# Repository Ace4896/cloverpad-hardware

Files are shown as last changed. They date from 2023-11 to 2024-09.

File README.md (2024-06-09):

# Cloverpad - Hardware

**NOTE**: This project is still a work-in-progress, this note will be removed once it's ready!

This repository contains the hardware designs for the Cloverpad, a 3-key keypad for osu! themed after [MORE MORE JUMP!](https://www.sekaipedia.org/wiki/MORE_MORE_JUMP!) from Project Sekai.

... picture of finished keypad ...

There are two PCB variants for this keypad:

- **Cloverpad HE**: PCB for use with hall effect switches (e.g. Wooting Lekker, Gateron KS-20), themed after [Haruka Kiritani](https://www.sekaipedia.org/wiki/Kiritani_Haruka).
- **Cloverpad MX**: PCB for use with regular MX-style mechanical switches, themed after [Minori Hanasato](https://www.sekaipedia.org/wiki/Hanasato_Minori).

## Usage

Make sure you have the following things installed:

- [FreeCAD 0.21](https://www.freecad.org/)
- [KiCad 8](https://www.kicad.org/) with the following plugins:
  - [marbastlib Keyboard Footprints](https://github.com/ebastler/marbastlib)
  - [KiCad JLCPCB Tools](https://github.com/Bouni/kicad-jlcpcb-tools) (if you're using JLC for manufacturing the PCB)

Clone the repository:

```bash
git clone git@github.com:Cloverpad/cloverpad-hardware.git
```

Then navigate to the folder for the revision you're interested in:

- [Rev. 2](./rev2)
- [Rev. 1](./rev1) (Cloverpad MX only; not recommended due to design flaws)

## Additional Files

These project files were used to help design the case and PCB:

- [**assets**](./assets): Miscellaneous assets - logos, character emotes etc.
- [**notes**](./notes): Personal notes for this project - you may find them useful if you're designing a keypad/keyboard of your own
- [**kle**](./kle): Keypad layouts generated by [Keyboard Layout Editor](http://www.keyboard-layout-editor.com/)

## Licensing

This project is licensed under [CERN-OHL-S-2.0](./LICENSE).

Below is a list of assets used from other projects:

- [Project Sekai: Colourful Stage!](https://www.colorfulstage.com/)
  - © SEGA / © Colorful Palette Inc. / © Crypton Future Media, INC.
  - This is a fan project and has no affiliation with SEGA, Colorful Palette, or Crypton Future Media.
  - Assets from MORE MORE JUMP! and its characters are used in the PCB designs.
- [ConstantinoSchillebeeckx/cherry-mx-switch](https://github.com/ConstantinoSchillebeeckx/cherry-mx-switch)
  - [MIT License](https://github.com/ConstantinoSchillebeeckx/cherry-mx-switch/blob/master/LICENSE)
  - The Cherry MX Switch 3D model is used in the minimal PCB.
- [ebastler/marbastlib](https://github.com/ebastler/marbastlib)
  - [CERN-OHL-P-2.0 License](https://github.com/ebastler/marbastlib/blob/main/LICENSE)
  - Various KiCad symbols and footprints are used in the PCB designs and the minimal PCB.

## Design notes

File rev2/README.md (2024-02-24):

# Cloverpad rev. 2

**NOTE**: This revision is still a work-in-progress, this note will be removed once it's ready!

This folder contains the hardware designs for the Cloverpad rev. 2. This is an incremental improvement over rev. 1, which resolves various issues with the 3D printed case.

Features:

- RP2040 MCU
- Cloverpad HE supports hot-swappable MX-style hall effect switches
- Cloverpad MX supports hot-swappable MX-style digital switches
- 3D printed case w/ threaded inserts

Required parts (for reference):

- 3D printed case + PCB
- USB Type-C cable
- 8x M2x6mm screws
- 8x M2x3mm threaded inserts
- Rubber feet

## Design Files

- [`cloverpad-case.FCStd`](./cloverpad-case.FCStd): FreeCAD 0.21 project for the 3D printed case.
- [`cloverpad-he-pcb`](./cloverpad-he-pcb): KiCad 8 project for the Cloverpad HE rev. 2 PCB.
- [`cloverpad-mx-pcb`](./cloverpad-mx-pcb): KiCad 8 project for the Cloverpad MX rev. 2 PCB.

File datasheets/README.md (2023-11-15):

# Datasheets

This folder contains datasheets for any important parts used in this project. The latest versions can be found on the manufacturers websites.

- **Hall Sensors**: [DRV5056](./drv5056/)
- **Key Switches**: [KS-20](./ks-20/) 
- **Microcontroller**: [RP2040](./rp2040/)

## Hall Sensor Compatibility

**NOTE**: As far as I'm aware, the KS-20 and Lekker switches use the same mechanism, and the only differences are branding, colours and spring weight. It should be possible to use them interchangably.

In the KS-20's datasheet, there are a few key pieces of information:

- Total Travel: 4.1 +/- 0.2mm
- Hall Sensor Placement: Back of PCB
- Orientation of Permanent Magnet: North pole at bottom of switch
- Magnetic Flux Density @ North Pole:
  - Initial Position: 102 +/- 15G
  - Total Travel Position: 905 +/- 80G

Based on the hall sensor placement and the orientation of the permanent magnet, it generates a positive field. In the diagram below (credit: [Texas Instruments - SLYT826](https://www.ti.com/document-viewer/lit/html/slyt826)), we can see this in the top-right case:

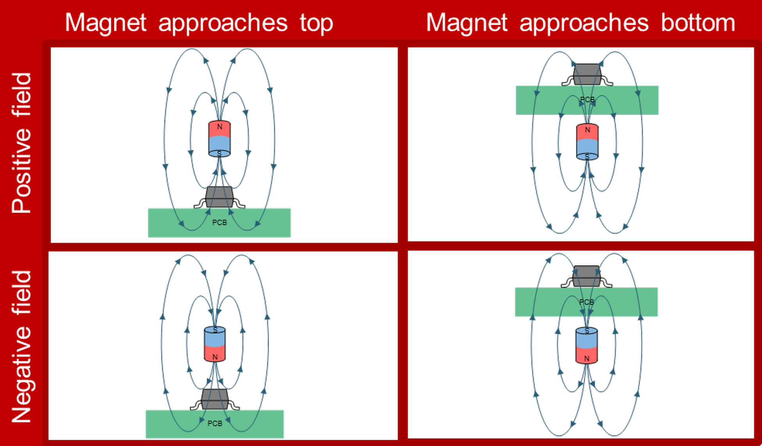
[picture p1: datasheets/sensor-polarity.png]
Sensor Polarity


This means that the hall sensor used needs to have the following properties:

- Detect a positive magnetic field (sometimes referred to as "south active")
- Produce a linear output so we can get analog readings
- Have a magnetic range that covers the maximum magnetic flux
- (Ideally) Unipolar i.e. reacts to only one pole / field direction
  - Technically, we can use a bipolar sensor that reacts to both poles, but we lose half of the resolution to a range of values that we won't use

The DRV5056A3 was chosen as it meets most of this criteria:

- Has a variant that can detect positive fields
- Generates a linear output
- Has a magnetic range of 79mT (790G)
- Is unipolar

The only downside is that we can't detect the full travel distance, since the analog output will be saturated before we reach the end of a keypress. If we wanted to detect the whole keypress, we could use the DRV5056A4 instead (magnetic range of 158mT / 1580G), but we lose a large section of the output voltage range as our maximum magnetic flux density is only 905G.

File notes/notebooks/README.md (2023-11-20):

# Jupyter Notebooks

This folder contains any Jupyter Notebooks I used while figuring out the calculations needed for this project.

- [magnet-distance](./magnet-distance.ipynb): Determining magnet distance from the magnetic flux value.

## Usage

You can preview these notebooks with GitHub's online viewer, but if you want to view/edit them locally, some setup is needed:

- Install Python 3.12 or higher
- [Create a virtual environment and activate it](https://packaging.python.org/en/latest/guides/installing-using-pip-and-virtual-environments/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):

```bash
python -m venv .venv

# Bash
source .venv/bin/activate

# PowerShell
.\.venv\bin\Activate.ps1
```

- Install requirements with `pip`:

```bash
pip install -r requirements.txt
```

- Start up Jupyter:

```bash
jupyter notebook
```

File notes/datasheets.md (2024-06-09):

# Datasheets

This folder contains datasheets several important parts used in this project. The latest versions can be found on the manufacturer websites.

- **Hall Sensors**:
  - [DRV5056](./drv5056/)
  - [SS39ET](./ss39et/)
- **Key Switches**:
  - [KS-20](./ks-20/) (original version)
- **Microcontrollers**:
  - [RP2040](./rp2040/)
- **Shunt Voltage References**:
  - [LM4040](./lm4040/)

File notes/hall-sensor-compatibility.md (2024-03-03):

# Hall Sensor Compatibility

**NOTE**: As far as I'm aware, the KS-20 and Lekker switches use the same mechanism, and the only differences are branding, colours and spring weight. It should be possible to use them interchangably.

In the KS-20's datasheet, there are a few key pieces of information:

- Total Travel: 4.1 +/- 0.2mm
- Hall Sensor Placement: Back of PCB
- Orientation of Permanent Magnet: North pole at bottom of switch
- Magnetic Flux Density @ North Pole:
  - Initial Position: 102 +/- 15G
  - Total Travel Position: 905 +/- 80G

Based on the hall sensor placement and the orientation of the permanent magnet, it generates a positive field. In the diagram below (credit: [Texas Instruments - SLYT826](https://www.ti.com/document-viewer/lit/html/slyt826)), we can see this in the top-right case:

Sensor Polarity

This means that the hall sensor used needs to have the following properties:

- Detect a positive magnetic field (sometimes referred to as "south active")
- Produce a linear output so we can get analog readings
- Have a magnetic range that covers the maximum magnetic flux
- (Ideally) Unipolar i.e. reacts to only one pole / field direction
  - Technically, we can use a bipolar sensor that reacts to both poles, but we lose half of the resolution to a range of values that we won't use

The DRV5056A3 was chosen as it meets most of the criteria:

- Has a variant that can detect positive fields
- Generates a linear output
- Has a magnetic range of 78mT (780G) at 3.3V
  - Technically, this range is not large enough, but in the ideal case, we'd only lose the last 0.2mm of travel on average, which makes this viable in practice
- Is unipolar

The DRV5056A4 would also work and be able to track the entire keystroke, but its reduced resolution means that 0.1mm precision is harder to achieve, especially at the top of the keystroke where the ADC values are smaller.

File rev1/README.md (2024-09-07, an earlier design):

# Cloverpad rev. 1

**NOTE**: I don't recommend using these designs; see the list [known issues](#known-issues) below.

This folder contains the hardware designs for the Cloverpad rev. 1.

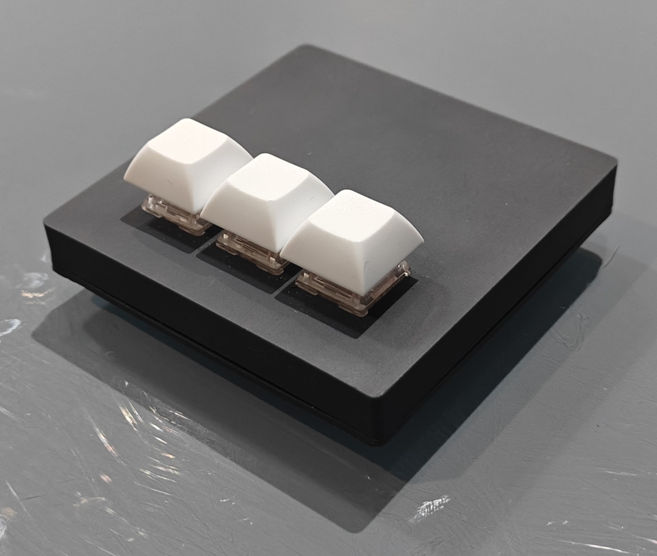
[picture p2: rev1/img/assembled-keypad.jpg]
Assembled Keypad

<br />
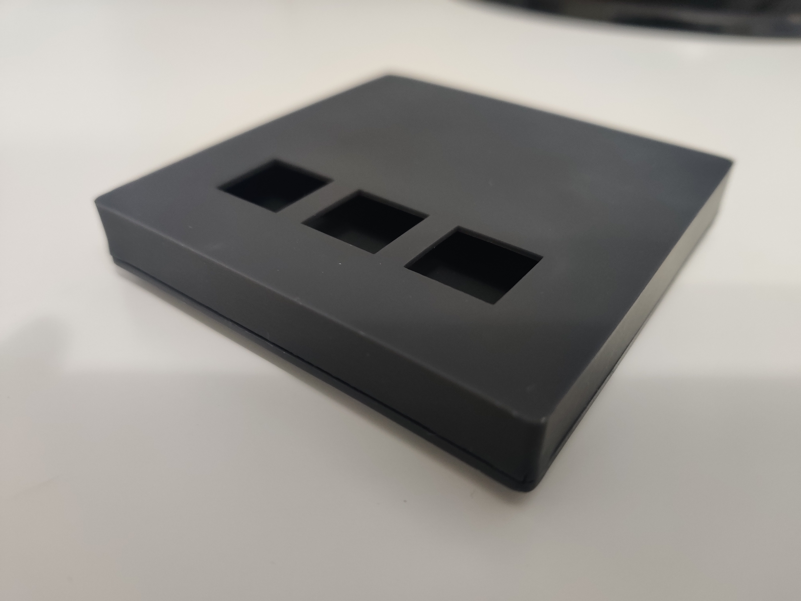
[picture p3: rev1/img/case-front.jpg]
Case Front

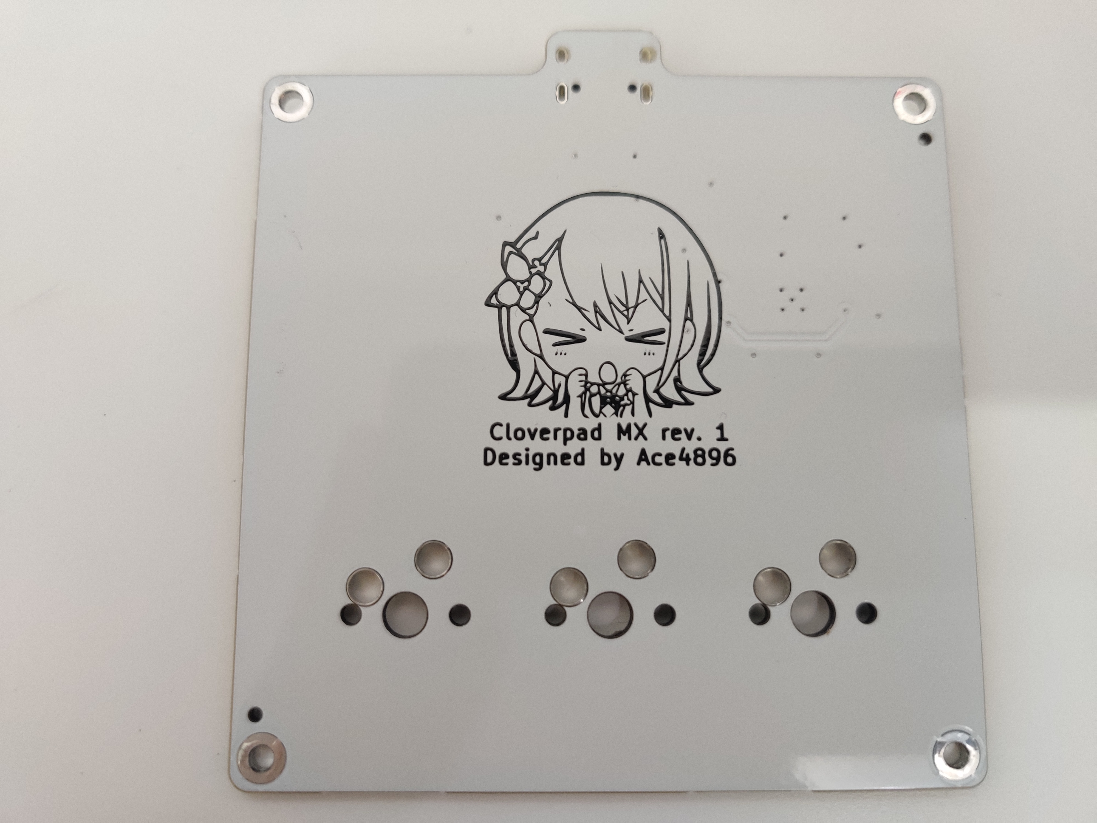
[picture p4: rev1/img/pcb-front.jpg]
PCB Front


[Photo Gallery](./img)

Features:

- RP2040 MCU
- Cloverpad MX PCB - supports hot-swappable MX-style digital switches
- 3D printed case w/ threaded inserts

Required parts (for reference):

- 3D printed case + PCB
- USB Type-C cable
- 8x M2x6mm screws
- 8x M2x3mm threaded inserts
- Rubber feet

## Design Files

- [`cloverpad-case.FCStd`](./cloverpad-case.FCStd): FreeCAD 0.21 project for the 3D printed case.
  - [`cloverpad-case-top.step`](./cloverpad-case-top.step) and [`cloverpad-case-bottom.step`](./cloverpad-case-bottom.step) are exported from this FreeCAD project
- [`cloverpad-mx-pcb`](./cloverpad-mx-pcb): KiCad 8 project for the Cloverpad MX rev. 1 PCB.

## Known Issues

There are a few major flaws with this design:

- When installing threaded inserts into the top/bottom pieces, the walls surrounding the threaded insert can crack
  - This is due to the supporting walls being too thin and/or the blind hole being too shallow
- On the Cloverpad MX PCB, it's impossible to solder switches directly to the PCB while the PCB is screwed in
  - This is an oversight that I completely missed; as a result, it only works in a hotswap configuration
  - Note that Mill-Max sockets are not compatible, as the holes for the switch pins are wider to accommodate for Kailh hotswap sockets
- There is a chance that the manufactured PCB won't boot into the flashed firmware, and infinitely boots into bootloader mode
  - Not sure what could cause this - faulty flash chip, bad reset / boot select circuit design, manufacturing error or user error

Rev. 2 will address these by:

- Increasing the supporting wall thickness to 3+ mm
  - To keep the case size small, the PCB screws need to be moved inwards slightly
- Moving all threaded inserts to the top pieces
  - This will allow direct soldering instead of hotswap for the Cloverpad MX
- Adjusting the routing around the boot select circuit and flash chip

## Other Potential Improvements

- **6-degree Typing Angle**
  - Having a slight incline (similar to a regular keyboard) would make this easier to use
- **Hiding Switch Tops**
  - An additional piece could be added above the switch plate, to hide the tops of the switches
  - This would also have the threaded inserts
- **Filling Empty Space**
  - Rev. 1's case has lots of empty space above and below the PCB
  - The top switch plate can be adjusted to only have 1.5mm thickness around the switch cutouts, and ~3.5mm elsewhere

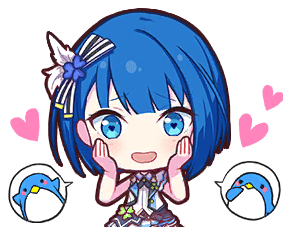
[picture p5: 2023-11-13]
assets/coloured/haruka-16.png

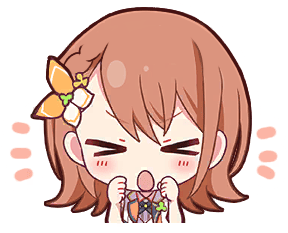
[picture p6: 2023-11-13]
assets/coloured/minori-02.png

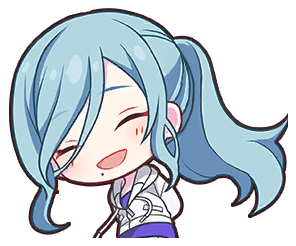
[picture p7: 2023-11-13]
assets/coloured/shizuku-16.png

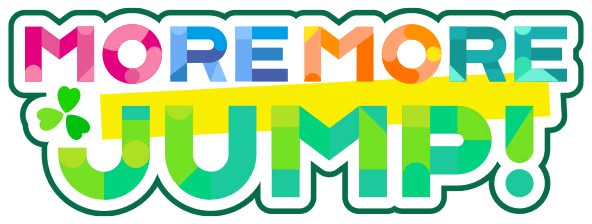
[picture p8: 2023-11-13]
assets/coloured/more-more-jump.png

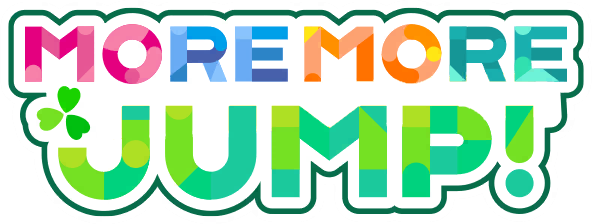
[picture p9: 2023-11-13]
assets/coloured/more-more-jump-no-yellow-bar.png

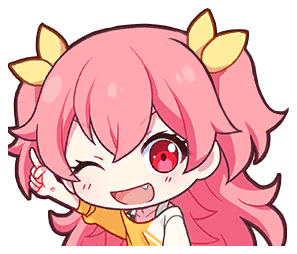
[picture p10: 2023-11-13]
assets/coloured/airi-14.png

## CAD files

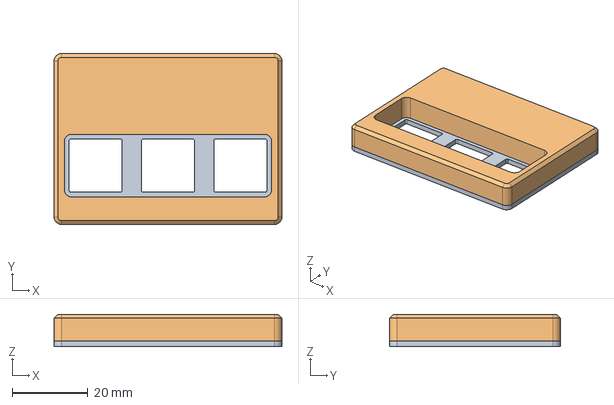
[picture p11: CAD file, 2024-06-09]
rev2/cloverpad-case.FCStd
60.0 x 45.0 x 8.50 mm
top-plate
top-shroud-chamfered

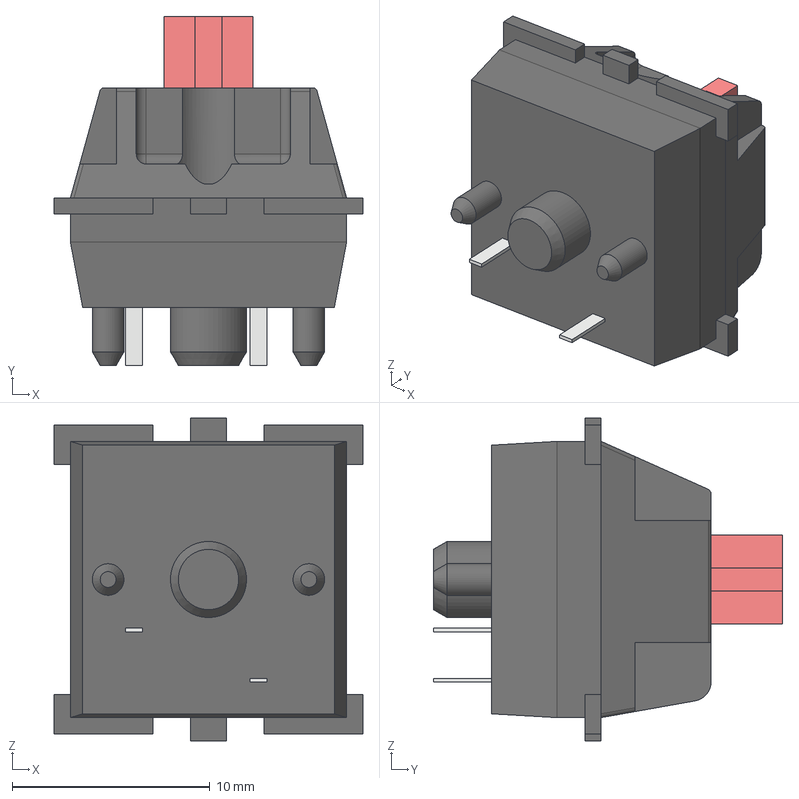
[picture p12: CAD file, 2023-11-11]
rev2/minimal-pcb/switch.step
15.6 x 17.7 x 16.3 mm

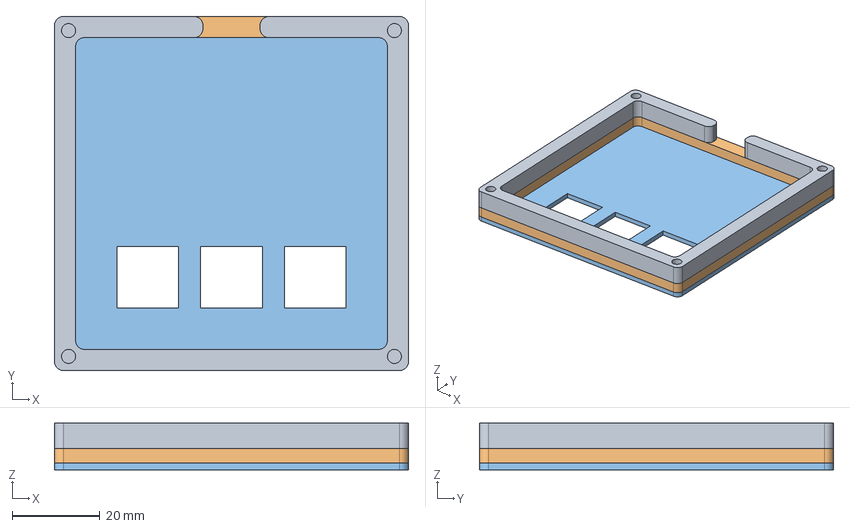
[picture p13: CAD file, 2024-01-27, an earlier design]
rev1/cloverpad-case-top.step
80.5 x 80.5 x 10.6 mm

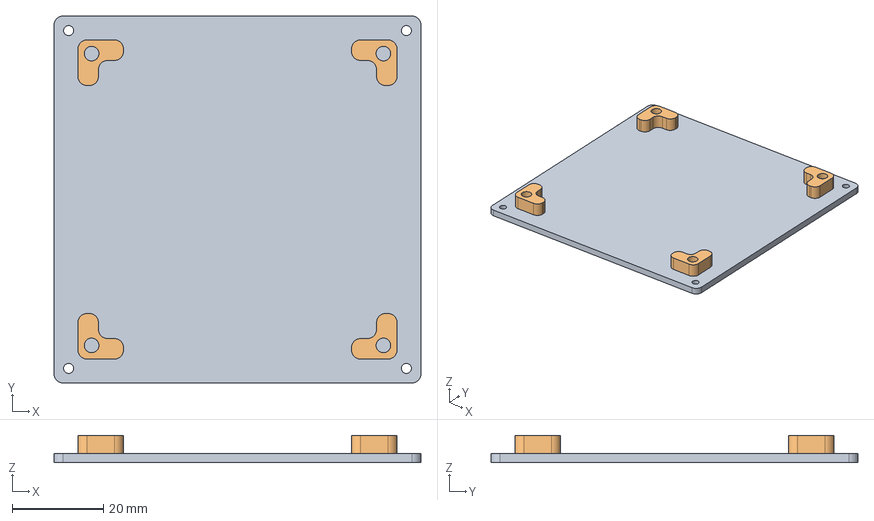
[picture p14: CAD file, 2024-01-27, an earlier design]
rev1/cloverpad-case-bottom.step
80.5 x 80.5 x 6.00 mm

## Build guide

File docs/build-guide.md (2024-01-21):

# Build Guide

**TODO**: Needs updating to match the new 3D printed case design

To build the keypad, you'll need:

- [`Standard Parts`](#standard-parts) - screws, rubber feet
- [Case](#case) - 3D printed case
- One of the PCBs:
  - [Cloverpad HE](#cloverpad-he-pcb-hall-effect-switches) if you're using hall effect mechanical switches
  - [Cloverpad MX](#cloverpad-mx-pcb-mechanical-switches) if you're using regular MX-style mechanical switches
- Mechanical switches for your chosen PCB
  - The Cloverpad HE is compatible with Wooting Lekker and Gateron KS-20 hall effect mechanical switches
  - The Cloverpad MX is compatible with any MX-style mechanical switch

## Standard Parts

It should be possible to find these parts from places like Amazon or electronics stores.

| Part | Quantity |
| :---: | :---: |
| 20mm Round M2 Standoff | 4 |
| M2 Screws | 8 |

**NOTE**: Before you get the case and PCB manufactured, you'll need to check the outer diameter of the M2 standoffs you're using. Usually, this is 3.2mm - the default mounting holes in the case and PCB have a diameter of 3.5mm, which should give enough room to account for tolerances.

If you do need to modify the mounting hole diameter, there are a few things to change:

- `cloverpad-case`:
  - Open the project in FreeCAD
  - In the tree view on the left, open `parameters` - this will open the spreadsheet view
  - Modify the value of `Standoff Outer Diameter / mm` so that it's slightly larger than the standoff's outer diameter
  - Export each layer of the case in the appropriate format
- `cloverpad-he` / `cloverpad-mx`:
  - Open the `.kicad_pro` file - this will open the project view
  - Open the `.kicad_sch` file - this will open the schematic view
  - In the schematic view:
    - Run the footprint assignment tool
    - Find and highlight H1, H2, H3 and H4
    - Change the mounting hole footprint to one that is slightly larger than the standoff's outer diameter
    - Save the footprint assignments
  - Open the `.kicad_pcb` file - this will open the PCB view
  - In the PCB view:
    - Update the PCB footprints from the schematic file
    - Ensure that the centre of each hole remained the same
    - Hide the H1, H2 etc. labels for the mounting holes
    - Use the KiCad JLCPCB extension to generate the new Gerbers, BOM and CPL files

## Case

The case design uses a stacked acrylic sandwich mount with the following layers:

| Part | Material | Quantity |
| :---: | :---: | :---: |
|  `top-spacer` | 3mm Acrylic | 2 |
| `plate` | 5mm Frosted Acrylic | 1 |
| `bottom-spacer` | 5mm Frosted Acrylic | 1 |
| `bottom-piece`  | 3mm Frosted Acrylic | 1 |

Frosted acrylic was chosen for the bottom pieces and plate as it can diffuse the RGB underglow lighting better, though regular acrylic is fine as well.

## Cloverpad HE PCB (Hall Effect Switches)

The Cloverpad HE PCB currently uses these parts:

| Component | Footprint | LCSC |
| :---: | :---: | :---: |
| 22pF Capacitor | C_0402_1005Metric |  C1555 |
| 100nF Capacitor | C_0402_1005Metric |  C1525 |
| 1uF Capacitor | C_0402_1005Metric |  C52923  |
| 10uF Capacitor | C_0603_1608Metric |  C19702  |
| 27 Ohm Resistor | R_0402_1005Metric |  C25100  |
| 100 Ohm Resistor | R_0402_1005Metric |  C25076  |
| 1k Ohm Resistor | R_0402_1005Metric |  C11702  |
| 5.1k Ohm Resistor | R_0402_1005Metric |  C25905  |
| USB-C Receptacle (USB 2.0) | USB_C_Receptacle_HRO_TYPE-C-31-M-12 | C165948  |
| 500mA Resettable Fuse | Fuse_1206_3216Metric | C170165  |
| ESD Protection (SRV05-4) | SOT-23-6-routable | C2836319 |
|  3.3V Voltage Regulator XC6206P332MR | SOT-23-3 |  C5446 |
| Microcontroller (RP2040) | QFN-56-1EP_7x7mm_P0.4mm_EP3.2x3.2mm |  C2040 |
| 12MHz Crystal | Crystal_SMD_3225-4Pin_3.2x2.5mm |  C9002 |
| 16MB Flash (W25Q16JVSSIQ) | SOIC-8_5.23x5.23mm_P1.27mm | C131025  |
| 5V Logic Level Converter (74AHCT1G125) | SOT-353_SC-70-5 | C151417  |
| Hall Sensor (DRV5056A4xDBZxQ1) | KS-20-1U-DRV5056 | C2152902 |
| Switch SMD RGB LEDs (SK6812MINI-E) | LED_MX_6028R | C5149201 |
| Underglow RGB LEDs (WS2812B) | LED_WS2812B_PLCC4_5.0x5.0mm_P3.2mm  | C2761795 |
| Push Buttons | SW_SPST_TL3342 | C318884  |

Some things to keep in mind for each component:

- **22pF Capacitors**: These are used for the crystal; if you're using a different crystal, you'll need to recalculate the values
- **Flash Memory**: Anything from Winbond's W25Q series should work; I've picked 16MB as it's more than enough for this project
- **Hall Sensor**: Use the A4 variant of the DRV5056 or DRV5056-Q1 (this should have 155mT / 1550G of magnetic range at 3.3V). The Q1 is usually more expensive as it's certified for automotive use
- **Underglow RGB LEDs**: Any 50x50mm variant of the WS2812B that operates on 5V logic should work
- **Switch SMD RGB LEDs**: Make sure that the LEDs have extruding pins which allow them to be reverse mounted

## Cloverpad MX PCB (Mechanical Switches)

The Cloverpad MX PCB currently uses these parts:

| Component | Footprint | LCSC |
| :---: | :---: | :---: |
| 22pF  Capacitor | C_0402_1005Metric |  C1555 |
| 100nF Capacitor | C_0402_1005Metric |  C1525 |
| 1uF Capacitor | C_0402_1005Metric |  C52923  |
| 10uF Capacitor | C_0603_1608Metric |  C19702  |
| 27 Ohm Resistor | R_0402_1005Metric |  C25100  |
| 1k Ohm Resistor | R_0402_1005Metric |  C11702  |
| 5k1 Ohm Resistor | R_0402_1005Metric |  C25905  |
| USB-C Receptable (USB 2.0) | USB_C_Receptacle_HRO_TYPE-C-31-M-12 | C165948  |
| 500mA Resettable Fuse | Fuse_1206_3216Metric | C170165  |
| ESD Protection (SRV05-4) | SOT-23-6-routable | C2836319 |
| 3.3V Voltage Regulator (XC6206P332MR) | SOT-23-3 |  C5446 |
| Microcontroller (RP2040) | QFN-56-1EP_7x7mm_P0.4mm_EP3.2x3.2mm |  C2040 |
| 12MHz Crystal | Crystal_SMD_3225-4Pin_3.2x2.5mm |  C9002 |
| 16MB Flash (W25Q16JVSSIQ) | SOIC-8_5.23x5.23mm_P1.27mm | C131025  |
| Kailh Hotswap Sockets | SW_MX_HS_1u | C5156480 |
| Push Buttons | SW_SPST_TL3342 | C318884  |

Some things to keep in mind for each component:

- **22pF Capacitors**: These are used for the crystal; if you're using a different crystal, you'll need to recalculate the values
- **Flash Memory**: Anything from Winbond's W25Q series should work; I've picked 16MB as it's more than enough for this project

## Ordering From JLCPCB (WIP)

- Use JLCPCB tool to generate required files
- Upload Gerber `.zip` file
- Enable PCB assembly and upload BOM + CPL files
  - Cross-check detected parts + pricing after uploading BOM - some may be missing
  - Cross-check component placement against rendered PCB

## Assembling the Keypad (WIP)

The layers on the keypad should be the following (top-to-bottom):

- Top Spacer
- Top Spacer
- Plate
- PCB
- Bottom Spacer
- Bottom Piece

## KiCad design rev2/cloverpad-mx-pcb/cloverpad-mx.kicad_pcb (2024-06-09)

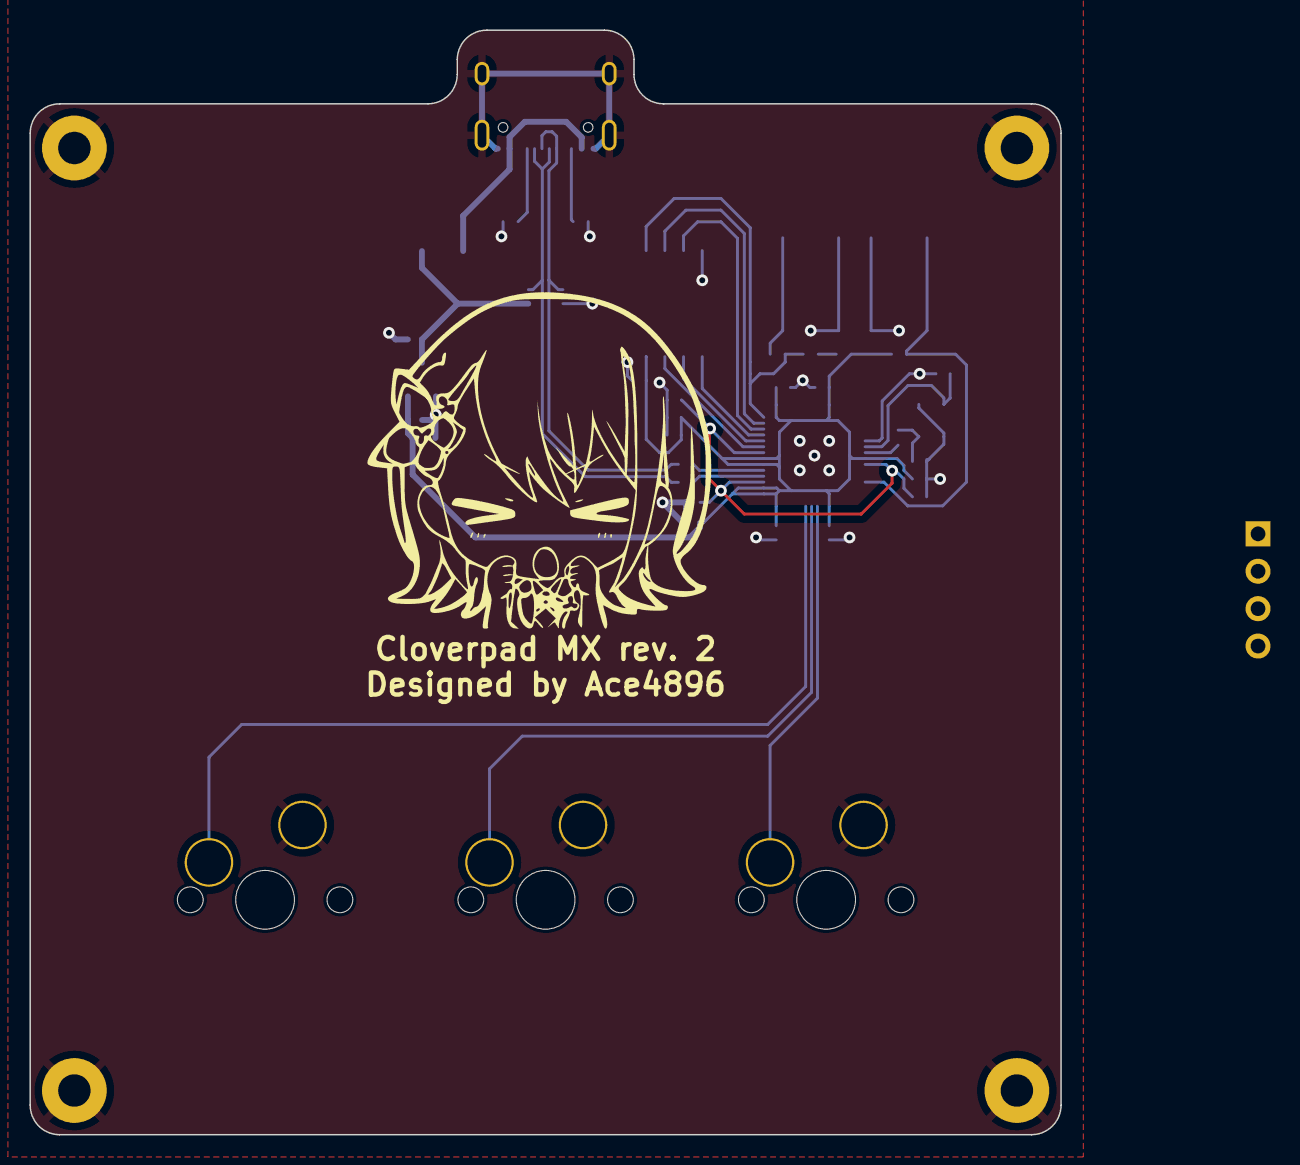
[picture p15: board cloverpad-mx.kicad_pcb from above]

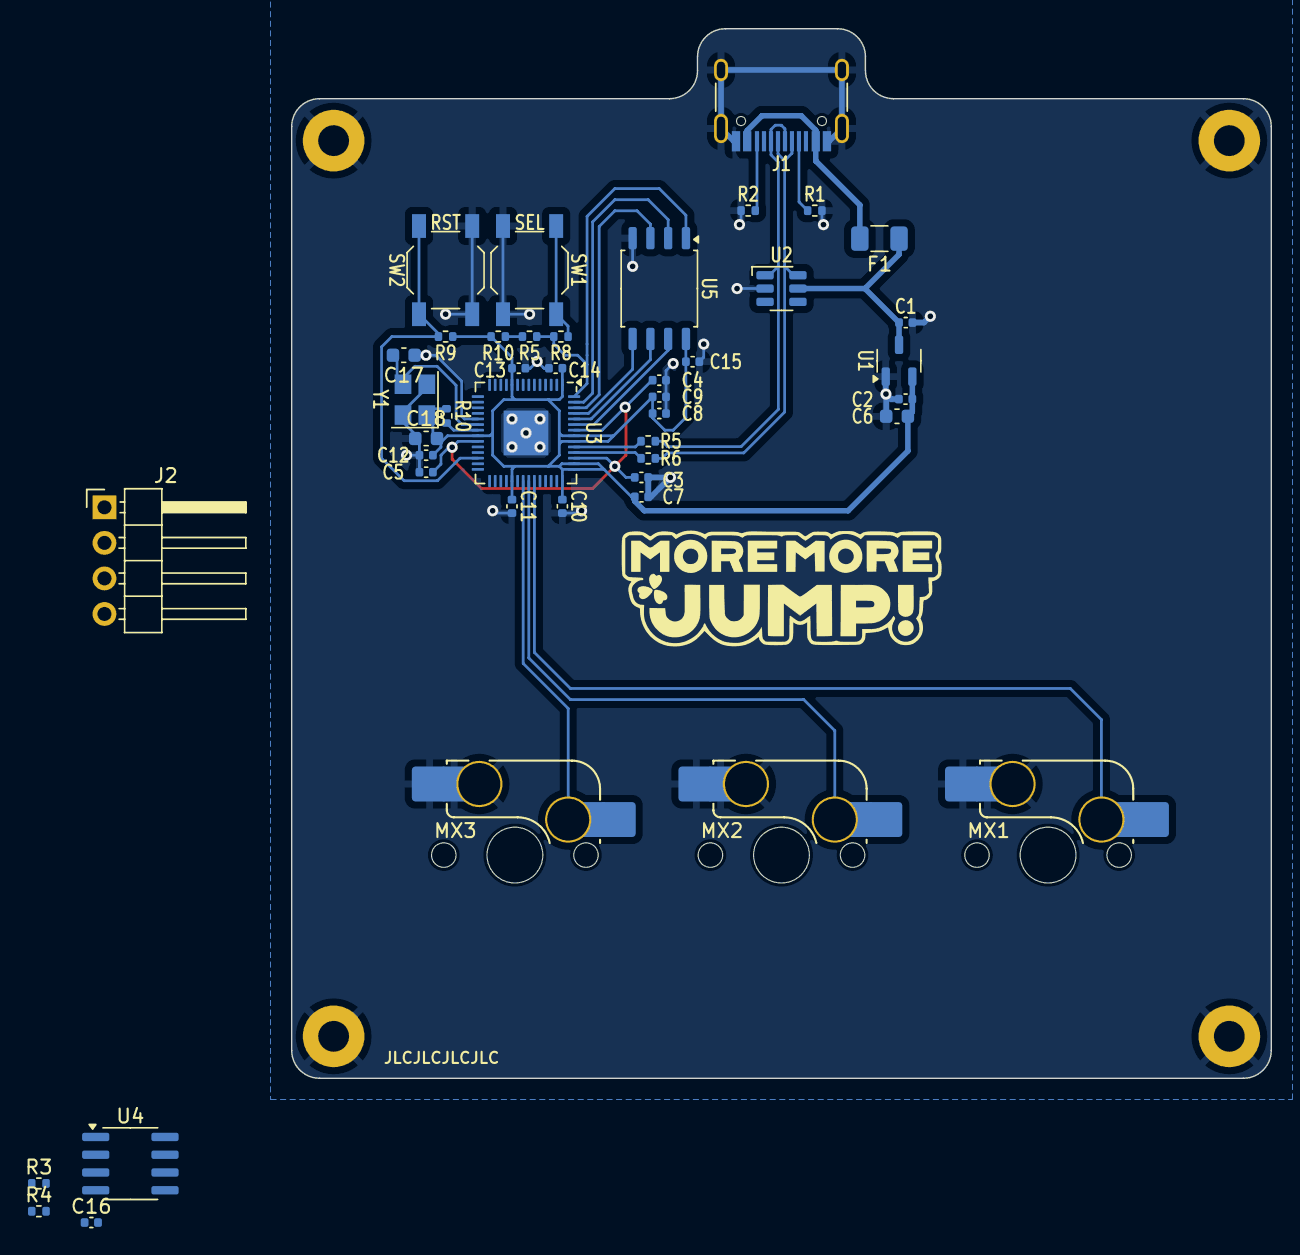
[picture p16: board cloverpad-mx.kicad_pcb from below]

Board: 2 copper layers, 70.0 x 75.0 mm, 47 parts (43 on the bottom side), 29 nets.

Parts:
C1, C2, C3, C7: 1uF; C_0402_1005Metric
C4, C5, C8, C9, C10, C11, C12, C13, C14, C15, C16: 100nF; C_0402_1005Metric
C6: 10uF; C_0603_1608Metric
C17, C18: 30pF; C_0603_1608Metric
F1: 500mA; Fuse_1206_3216Metric
H1, H2, H3, H4: Mounting Hole; MountingHole_2.2mm_M2_Pad
J1: USB_C_Receptacle_USB2.0; USB_C_Receptacle_HRO_TYPE-C-31-M-12
J2: Conn_01x04; PinHeader_1x04_P2.54mm_Horizontal
MX1, MX2, MX3: MX_SW_HS; SW_MX_HS_CPG151101S11_1u
R1, R2, R3, R4, R10: 5k1; R_0402_1005Metric
R5, R6: 27; R_0402_1005Metric
R5#2: 10k (DNF); R_0402_1005Metric
R8, R9, R10#2: 1k; R_0402_1005Metric
SW1, SW2: SW_Push; SW_SPST_TL3342
U1: XC6206P332MR; SOT-23-3
U2: SRV05-4; SOT-23-6-routable
U3: RP2040; QFN-56-1EP_7x7mm_P0.4mm_EP3.2x3.2mm
U4: AT24C32; SOIC-8_3.9x4.9mm_P1.27mm
U5: W25Q128JVS; SOIC-8_5.23x5.23mm_P1.27mm
Y1: 12MHz; Crystal_SMD_3225-4Pin_3.2x2.5mm

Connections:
+1V1: C3.1, C4.1, C5.1, U3.23 (DVDD), U3.45 (VREG_VOUT), U3.50 (DVDD)
+3V3: C2.1, C6.1, C7.1, C8.1, C9.1, C10.1, C11.1, C12.1, C13.1, C14.1, C15.1, C16.1, J2.1, R3.1, R4.1, R5#2.1, R9.1, R10.1, U1.2 (VO), U3.1 (IOVDD), U3.10 (IOVDD), U3.22 (IOVDD), U3.33 (IOVDD), U3.42 (IOVDD), U3.43 (ADC_AVDD), U3.44 (VREG_IN), U3.48 (USB_VDD), U3.49 (IOVDD), U4.8 (VCC), U5.8 (VCC)
+5V: C1.1, F1.1, U1.3 (VI), U2.5 (VP)
/EEPROM_SCL: R4.2, U3.3 (GPIO1), U4.6 (SCL)
/EEPROM_SDA: R3.2, U3.2 (GPIO0), U4.5 (SDA)
/K1: MX1.1, U3.40 (GPIO28_ADC2)
/K2: MX2.1, U3.39 (GPIO27_ADC1)
/K3: MX3.1, U3.38 (GPIO26_ADC0)
/QSPI_SCLK: U3.52 (QSPI_SCLK), U5.6 (CLK)
/QSPI_SD0: U3.53 (QSPI_SD0), U5.5 (DI(IO0))
/QSPI_SD1: U3.55 (QSPI_SD1), U5.2 (DO(IO1))
/QSPI_SD2: U3.54 (QSPI_SD2), U5.3 (IO2)
/QSPI_SD3: U3.51 (QSPI_SD3), U5.7 (IO3)
/QSPI_SS: R5#2.2, R8.2, U3.56 (QSPI_SS), U5.1 (~CS)
/RUN: R9.2, SW2.2, U3.26 (RUN)
/SWCLK: J2.2, U3.24 (SWCLK)
/SWD: J2.3, U3.25 (SWD)
/USB_D+: J1.A6 (D+), J1.B6 (D+), R5.1, U2.1 (IO1)
/USB_D-: J1.A7 (D-), J1.B7 (D-), R6.1, U2.6 (IO4)
/USB_DM: R6.2, U3.46 (USB_DM)
/USB_DP: R5.2, U3.47 (USB_DP)
/XIN: C17.2, U3.20 (XIN), Y1.3
/XOUT: R10#2.2, U3.21 (XOUT)
GND: C1.2, C2.2, C3.2, C4.2, C5.2, C6.2, C7.2, C8.2, C9.2, C10.2, C11.2, C12.2, C13.2, C14.2, C15.2, C16.2, C17.1, C18.1, H1.1, H2.1, H3.1, H4.1, J1.A1 (GND), J1.A12 (GND), J1.B1 (GND), J1.B12 (GND), J1.S1 (SHIELD), J2.4, MX1.2, MX2.2, MX3.2, R1.2, R2.2, SW1.1, SW2.1, U1.1 (GND), U2.2 (VN), U3.19 (TESTEN), U3.57 (GND), U4.1 (A0), U4.2 (A1), U4.3 (A2), U4.4 (GND), U4.7 (WP), U5.4 (GND), Y1.2, Y1.4
unnamed: C18.2, R10#2.1, Y1.1
unnamed: F1.2, J1.A4 (VBUS), J1.A9 (VBUS), J1.B4 (VBUS), J1.B9 (VBUS)
unnamed: J1.A5 (CC1), R1.1
unnamed: J1.B5 (CC2), R2.1
unnamed: R8.1, SW1.2

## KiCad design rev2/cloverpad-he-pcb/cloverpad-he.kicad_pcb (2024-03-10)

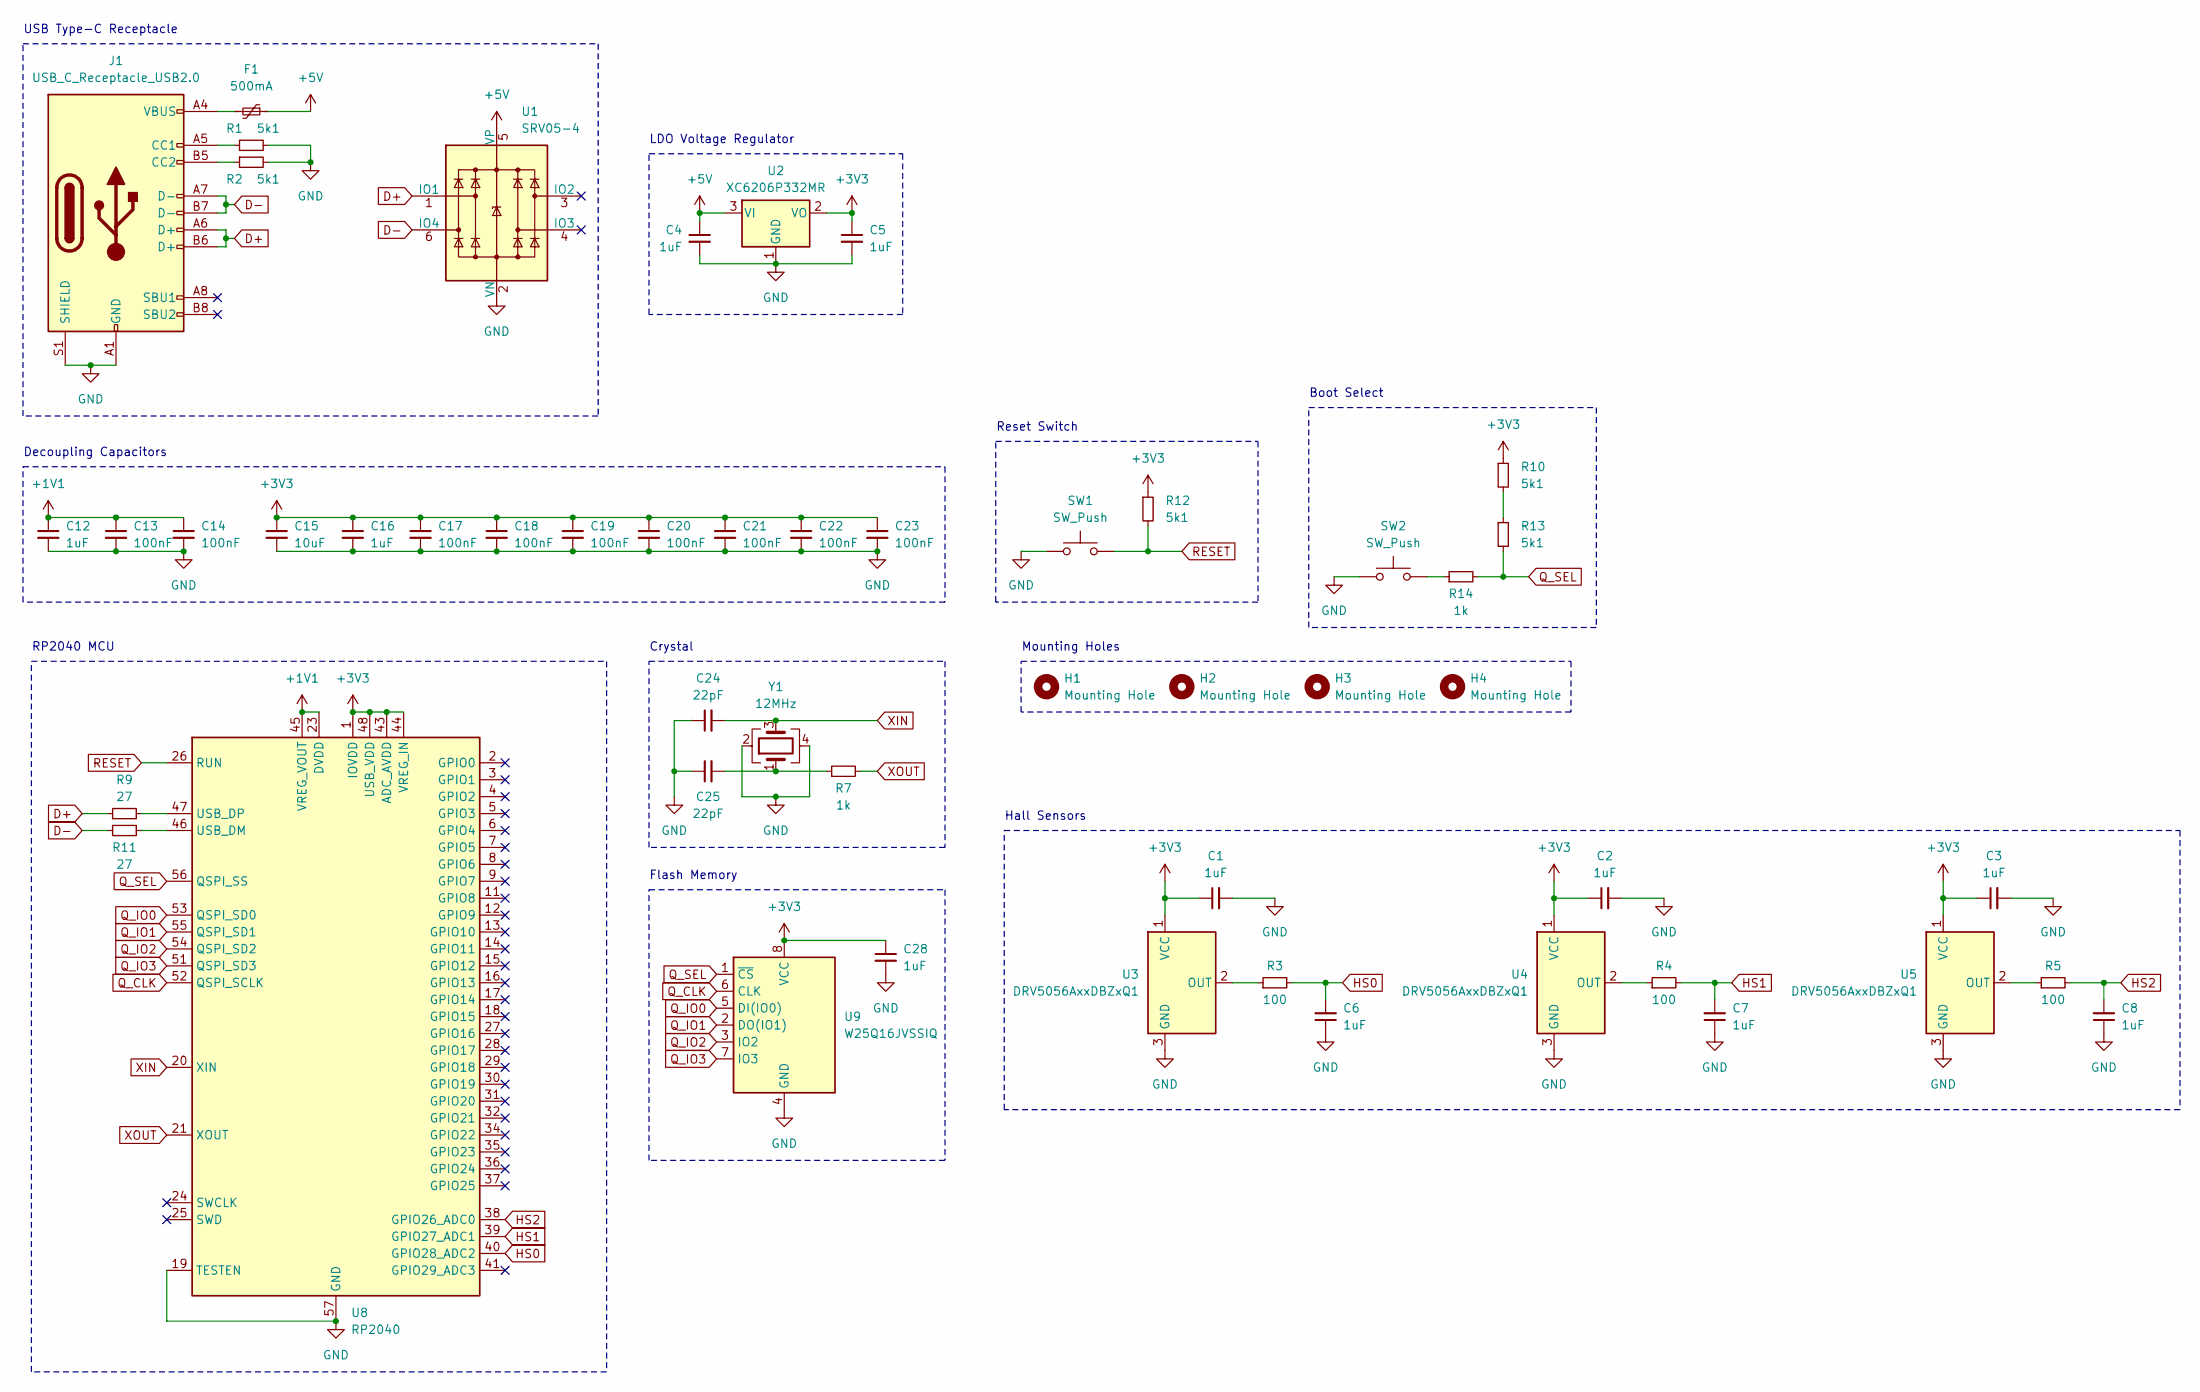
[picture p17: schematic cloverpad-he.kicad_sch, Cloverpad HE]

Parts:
C1, C2, C3, C4, C5, C6, C7, C8, C12, C16, C28: 1uF; C_0402_1005Metric; LCSC C52923
C13, C14, C17, C18, C19, C20, C21, C22, C23: 100nF; C_0402_1005Metric; LCSC C1525
C15: 10uF; C_0603_1608Metric; LCSC C19702
C24, C25: 22pF; C_0402_1005Metric; LCSC C1555
F1: 500mA; Fuse_1206_3216Metric; LCSC C170165
H1, H2, H3, H4: Mounting Hole; MountingHole_2.2mm_M2
J1: USB_C_Receptacle_USB2.0; USB_C_Receptacle_HRO_TYPE-C-31-M-12; LCSC C165948
R1, R2, R10, R12, R13: 5k1; R_0402_1005Metric; LCSC C25905
R3, R4, R5: 100; R_0402_1005Metric; LCSC C25076
R7, R14: 1k; R_0402_1005Metric; LCSC C11702
R9, R11: 27; R_0402_1005Metric; LCSC C25100
SW1, SW2: SW_Push; SW_SPST_TL3342; LCSC C318884
U1: SRV05-4; SOT-23-6-routable; LCSC C2836319
U2: XC6206P332MR; SOT-23-3; LCSC C5446
U3, U4, U5: DRV5056AxxDBZxQ1; KS-20-1U-DRV5056; LCSC C2152965
U8: RP2040; QFN-56-1EP_7x7mm_P0.4mm_EP3.2x3.2mm; LCSC C2040
U9: W25Q16JVSSIQ; SOIC-8_5.23x5.23mm_P1.27mm; LCSC C131025
Y1: 12MHz; Crystal_SMD_3225-4Pin_3.2x2.5mm; LCSC C9002

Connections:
+1V1: C12.1, C13.1, C14.1, U8.23 (DVDD), U8.45 (VREG_VOUT), U8.50 (DVDD)
+3V3: C1.1, C2.1, C3.1, C5.1, C15.1, C16.1, C17.1, C18.1, C19.1, C20.1, C21.1, C22.1, C23.1, C28.1, R10.1, R12.1, U2.2 (VO), U3.1 (VCC), U4.1 (VCC), U5.1 (VCC), U8.1 (IOVDD), U8.10 (IOVDD), U8.22 (IOVDD), U8.33 (IOVDD), U8.42 (IOVDD), U8.43 (ADC_AVDD), U8.44 (VREG_IN), U8.48 (USB_VDD), U8.49 (IOVDD), U9.8 (VCC)
+5V: C4.1, F1.1, U1.5 (VP), U2.3 (VI)
D+: J1.A6 (D+), J1.B6 (D+), R9.1, U1.1 (IO1)
D-: J1.A7 (D-), J1.B7 (D-), R11.1, U1.6 (IO4)
GND: C1.2, C2.2, C3.2, C4.2, C5.2, C6.1, C7.1, C8.1, C12.2, C13.2, C14.2, C15.2, C16.2, C17.2, C18.2, C19.2, C20.2, C21.2, C22.2, C23.2, C24.1, C25.1, C28.2, J1.A1 (GND), J1.A12 (GND), J1.B1 (GND), J1.B12 (GND), J1.S1 (SHIELD), R1.2, R2.2, SW1.1, SW2.1, U1.2 (VN), U2.1 (GND), U3.3 (GND), U4.3 (GND), U5.3 (GND), U8.19 (TESTEN), U8.57 (GND), U9.4 (GND), Y1.2, Y1.4
HS0: C6.2, R3.2, U8.40 (GPIO28_ADC2)
HS1: C7.2, R4.2, U8.39 (GPIO27_ADC1)
HS2: C8.2, R5.2, U8.38 (GPIO26_ADC0)
unnamed: C25.2, R7.1, Y1.1
unnamed: F1.2, J1.A4 (VBUS), J1.A9 (VBUS), J1.B4 (VBUS), J1.B9 (VBUS)
unnamed: J1.A5 (CC1), R1.1
unnamed: J1.B5 (CC2), R2.1
unnamed: R10.2, R13.1
unnamed: R14.1, SW2.2
unnamed: R3.1, U3.2 (OUT)
unnamed: R4.1, U4.2 (OUT)
unnamed: R5.1, U5.2 (OUT)
unnamed: R11.2, U8.46 (USB_DM)
unnamed: R9.2, U8.47 (USB_DP)
Q_CLK: U8.52 (QSPI_SCLK), U9.6 (CLK)
Q_IO0: U8.53 (QSPI_SD0), U9.5 (DI(IO0))
Q_IO1: U8.55 (QSPI_SD1), U9.2 (DO(IO1))
Q_IO2: U8.54 (QSPI_SD2), U9.3 (IO2)
Q_IO3: U8.51 (QSPI_SD3), U9.7 (IO3)
Q_SEL: R13.2, R14.2, U8.56 (QSPI_SS), U9.1 (~CS)
RESET: R12.2, SW1.2, U8.26 (RUN)
XIN: C24.2, U8.20 (XIN), Y1.3
XOUT: R7.2, U8.21 (XOUT)

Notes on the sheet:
Reset Switch
USB Type-C Receptacle
Mounting Holes
Decoupling Capacitors
LDO Voltage Regulator
Hall Sensors
RP2040 MCU
Flash Memory
Boot Select
Crystal

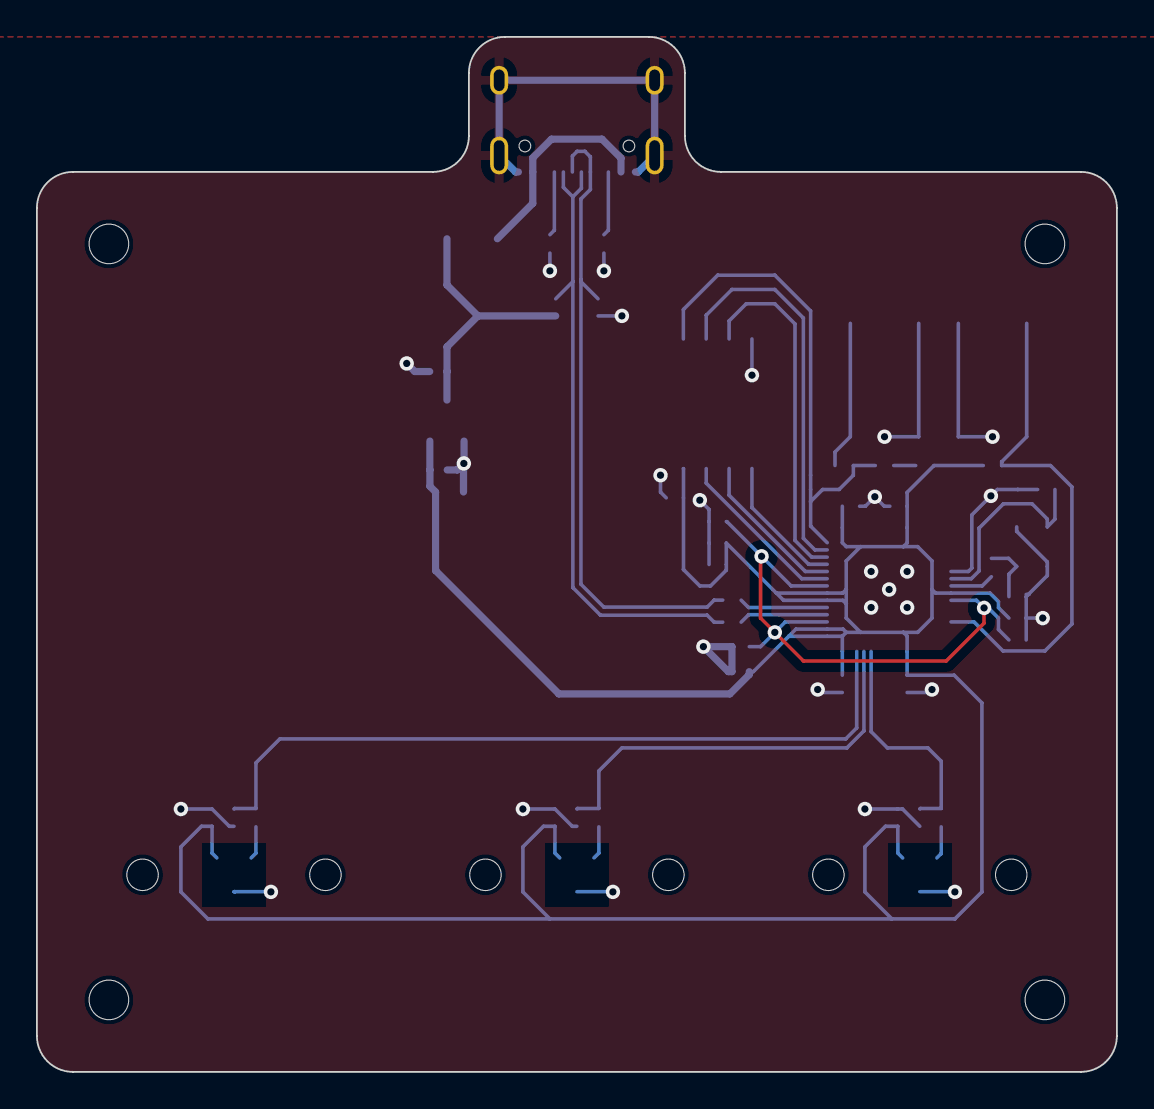
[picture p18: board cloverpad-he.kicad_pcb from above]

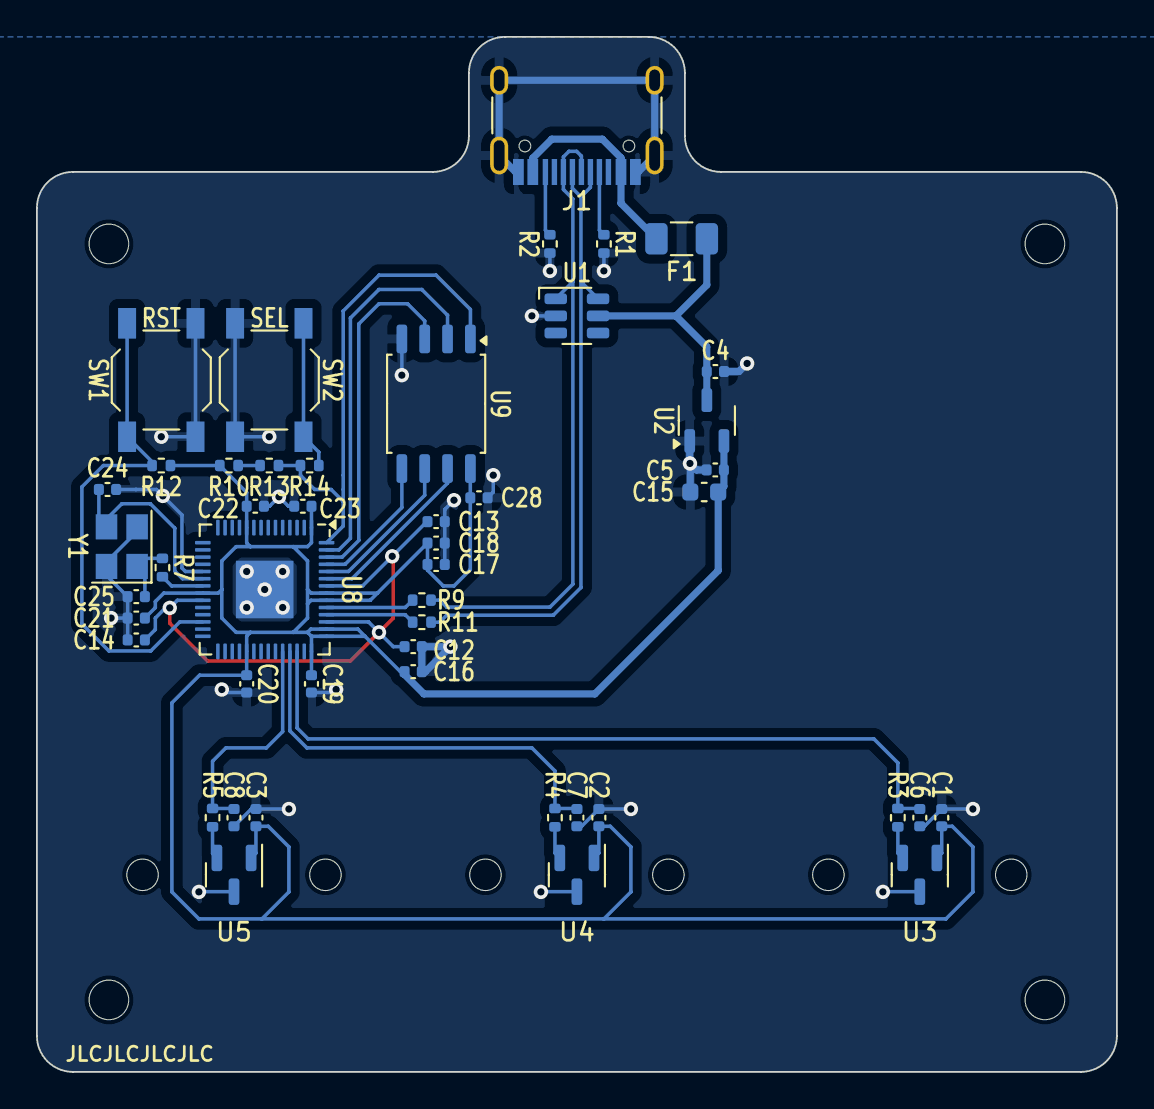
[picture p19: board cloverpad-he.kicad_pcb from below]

Board: 2 copper layers, 60.0 x 57.5 mm, 51 parts (47 on the bottom side), 29 nets.

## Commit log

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2023-11-05 feat: initial schematic
    has the bare minimum components for a working keypad.
    [pcb.kicad_pcb, pcb.kicad_sch]
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2023-11-05 refactor: use marbastlib footprint for in-switch LED
    to make it easier to align.
    [pcb.kicad_pcb, pcb.kicad_sch]
2023-11-05 feat: initial attempt at laying out pcb
    routing will be tricky - might need a 4 layer pcb due to the mixed voltages...
    probably better to remove the in-switch LEDs for the time being...
    [pcb.kicad_pcb, pcb.kicad_sch]
2023-11-05 feat: initial attempt at placing and routing key components
    [pcb.kicad_pcb, pcb.kicad_sch]
2023-11-06 fix: add 3.3v to 5v logic conversion
    this uses the 74AHCT1G125. there are values that can step up multiple pins at once, but it seems cheaper to just use individual ones. it should also be easier to route, as the logic level conversion can be placed next to each relevant location.
    [pcb.kicad_sch]
2023-11-06 feat: routing for rgb leds + logic level conversion
    [pcb.kicad_pcb]
2023-11-06 feat: most of pcb routed
    still need to find a location for the debug header and reset switch, as they're kinda linked together...
    after this, I can think about routing the LED logic lines and hall sensor power lines.
    [pcb.kicad_pcb]
2023-11-07 feat: fully connected pcb
    ended up removing the debug header - I don't think these appear in production boards anyway, so should be OK.
    there's probably a better way to route the analog lines, but I couldn't come up with anything for it...
    [pcb.kicad_pcb, pcb.kicad_sch]
2023-11-07 feat: add m2 screw holes the footprint already takes the 4mm width of the standoffs into account, so should be OK as long as I position it correctly in CAD.
    [pcb.kicad_pcb, pcb.kicad_sch]
2023-11-07 chore: add title + revision to pcb design
    [pcb.kicad_pcb]
2023-11-11 feat: add minimal pcb design for case measurements
    [minimal-pcb.kicad_pcb, minimal-pcb.kicad_sch, switch.step]
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2023-11-11 fix: move switches slightly higher, to move away from screw holes
    [case.FCStd, minimal-pcb.kicad_pcb]
2023-11-11 chore: setup new project based on minimal pcb also re-arranged it since I may make a digital version as well.
    [analog.kicad_pcb, analog.kicad_sch, pcb.kicad_pcb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]
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2023-11-12 feat: routing for new pcb required shuffling some components around, but this casn be accounted for in software, so it's not a big deal.
    [analog.kicad_pcb, analog.kicad_sch]
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2023-11-14 fix: fix haruka-16 emote on pcb and adjust alignment
    [analog.kicad_pcb]
2023-11-14 chore: remove pcb artwork for now since I want to try re-routing the PCB again.
    [analog.kicad_pcb]
2023-11-14 refactor: move mcu to top left
    the routing is a lot more compact for the key components, and it looks like I'll have more room to route the relevant data lines.
    [analog.kicad_pcb]
2023-11-14 refactor: new pcb layout
    more compact and has fewer crossing lines. can definitely shrink the PCB, but I've picked this size so it's possible to see the design from the top.
    [analog.kicad_pcb, analog.kicad_sch]
2023-11-14 refactor: create custom footprint for KS-20 w/ DRV5056
    this includes a custom silkscreen, reference value and a rule area to disallow copper fills in the middle of the sensor.
    [analog.kicad_pcb, analog.kicad_sch]
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2023-11-15 fix: resolve silkscreenm overlaps in keyswitch area
    [analog.kicad_pcb]
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2023-11-15 refactor: route analog +3v3 without going underneath LEDs just realised that it may cause some noise in the supply.
    [analog.kicad_pcb]
2023-11-15 feat: add bottom piece cutouts for pcb buttons
    I ended up moving the buttons slightly so it appears more evenly spaced.
    There's also silkscreen labels indicating which buttons they are, whcih should make instructions a bit easier.
    [analog.kicad_pcb, case.FCStd]
2023-11-15 fix: resolve all silkscreen overlaps
    [analog.kicad_pcb]
2023-11-15 fix: resolve footprint mismatch warnings
    [analog.kicad_pcb, analog.kicad_sch]
2023-11-15 fix: attempt 2 at fixing mismatched footprints
    [analog.kicad_pcb]
2023-11-15 chore: export 3d step file for pcb
    measurements look good; no issues with component clearance and the
    bottom cutouts line up with the buttons.
    [case.FCStd]
2023-11-15 refactor: use 1206 footprint for fuse
    there are more polyfuses with 500mA hold current at this size.
    [analog.kicad_pcb, analog.kicad_sch]
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2023-11-15 feat: setup jlcpcb tools
    seems to be working - the generated gerbers, bom and cpl are correct.
    the DRV5056 isn't being picked up, but it's likely just because it's out of stock.
    [analog.kicad_pcb]
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2023-11-15 fix: ensure that mounting holes are excluded from bom
    [analog.kicad_sch]
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2023-11-15 fix: centre minori's emote
    [analog.kicad_pcb]
2023-11-15 docs: fix copy-paste error for kicad 7 link
2023-11-15 fix: add missing saved details
    [analog.kicad_pcb]
2023-11-16 fix: adjust ks-20 footprints so they're on front side by default
    so that when it's flipped, the components appear on the back side in the BOM. this way, it can be assembled with the rest of the components
    [analog.kicad_pcb]
2023-11-16 fix: add a couple of missed changes
    [analog.kicad_pcb]
2023-11-16 fix: convert case mounting holes to 3.5mm diameter hexagons
    [case.FCStd]
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2023-11-19 docs: fix quantity of m2 screws in build guide
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2023-11-19 fix: rework clover in mmj logo
    [analog.kicad_pcb]
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2023-11-21 fix: adjust ks-20 magnet dimensions
    still can't get the right magnet profile...
2023-11-28 fix: use grounded 3.5mm mounting holes on pcb didn't realise that the pads are used for grounding... definitely worth adding them in.
    [pcb.kicad_pcb, pcb.kicad_sch]
2023-11-28 fix: use padded 3.5mm mounting holes in minimal PCB
    [minimal-pcb.kicad_pcb, minimal-pcb.kicad_sch]
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2023-11-28 fix: use rounded 3.5mm mounting holes in case
    also use the new 3d models for the PCBs. nice to see that all of them line up now.
    [case.FCStd]
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2023-11-28 fix: move JLC order number placeholder
    so it doesn't overlap with the pad.
    [pcb.kicad_pcb]
2023-11-28 fix: remove remaining references to hex standoffs
    [case.FCStd]
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2023-12-02 fix: use DRV5056A4
    not in stock at JLC, but it's the better option as it can detect the full range while being better than any bipolar options.
    [pcb.kicad_pcb, pcb.kicad_sch]
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2023-12-22 feat: add minoripad
    this is a simplified version of the harukapad, with regular MX switches and no RGB effects.
    will be used to validate my case design.
    [harukapad.kicad_pcb, harukapad.kicad_sch, minoripad.kicad_pcb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]
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2023-12-22 fix: correct title in minoripad schematic
    [minoripad.kicad_sch]
2023-12-23 fix(harukapad): connect mounting holes to ground, fix incorrect footprint
    at some point, it changed back to the SOT-23 footprint, so the holes would've been missing...
    [harukapad.kicad_pcb, harukapad.kicad_sch]
2023-12-24 fix: increase size of usb-c cutout
    my constraint was placed incorrectly, so the cutout clipped into the usb-c's 3d model...
    [cloverpad-case.FCStd]
2023-12-24 fix: use south facing switches in minimal PCB
    didn't notice until I saw the positioning of the hotswap sockets on the minoripad PCB...
    [cloverpad-case.FCStd, minimal-pcb.kicad_pcb]
2023-12-24 chore: export case files to dxf and step for 3.5mm hole diameter
    [cloverpad-case-bottom-piece.dxf, cloverpad-case-bottom-spacer.dxf, cloverpad-case-plate.dxf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]
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2024-01-21 chore: update minimal pcb
    got the usb cutout dimensions wrong on the pcb... need to fix it
    [cloverpad-case.FCStd, minimal-pcb.kicad_pcb, minimal-pcb.kicad_sch]
2024-01-21 fix: add screw holes to top piece
    [cloverpad-case.FCStd]
2024-01-21 fix: correct usb cutout distance on minoripad
    [minoripad-v2.kicad_pcb]
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2024-01-26 chore: remove rgb from Cloverpad HE pcb
    I want to keep the cost down; including RGB means that standard PCB assembly is needed, which causes the price to spike...
    [cloverpad-he.kicad_pcb, cloverpad-he.kicad_sch]
2024-01-26 fix: use proper constraints on bottom plate in case
    [cloverpad-case.FCStd]
2024-01-26 fix: use 70x70mm pcb size and 80x80mm case
    proides enough clearance all of the parts, as I've already managed to route traces this way.
    [cloverpad-case.FCStd, minimal-pcb.kicad_pcb]
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2024-01-26 chore: remove foot for 6 degree angle
    not sure how will this will print if it's attached... but it's probably better if the keypad is flat anyway.
    [cloverpad-case.FCStd]
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2024-01-26 fix: port pcb shape changes to cloverpad mx
    [cloverpad-mx.kicad_pcb, cloverpad-mx.kicad_sch]
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2024-01-26 fix: swap positions of MX1 and MX3 on cloverpad mx
    makes more sense as when viewed from the front, MX1 is the leftmost switch.
    [cloverpad-mx.kicad_pcb, cloverpad-mx.kicad_sch]
2024-01-26 fix: swap positions of HS0 and HS2 on cloverpad he
    same as on cloverpad mx - this puts HS0 on the leftmost side.
    [cloverpad-he.kicad_pcb, cloverpad-he.kicad_sch]
2024-01-26 fix: port pcb size changes to cloverpad he
    since there's no RGB now, it's possible to route the analog signals more directly.
    [cloverpad-he.kicad_pcb, cloverpad-he.kicad_sch]
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2024-01-26 fix: remove border from DRV5056 footprint
    don't think I need this...
    [cloverpad-he.kicad_pcb]
2024-01-26 fix: normalise position of JLC order number on PCB
    [cloverpad-he.kicad_pcb]
2024-01-27 refactor: simplify pcb mounting holes on bottom piece
    less material used, so it's cheaper to print.
    [cloverpad-case-bottom.step, cloverpad-case.FCStd]
2024-01-27 fix: adjust case design based on final parts list
    [cloverpad-case-bottom.step, cloverpad-case-top.step, cloverpad-case.FCStd]
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2024-01-27 fix: add rotations for cloverpad mx
    [cloverpad-mx.kicad_pcb, rotations.csv]
2024-01-27 fix: increase case size slightly
    if the top half is slightly too small and the pcb is slightly too large, the case won't fit together...
    [cloverpad-case-bottom.step, cloverpad-case-top.step, cloverpad-case.FCStd]
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2024-03-03 fix: use DRV5056A3 instead of A4
    after some testing, losing the bottom 0.2mm of travel isn't a huge problem, and it's better to increase the resolution for the upper part of the keystroke instead.
    [cloverpad-he.kicad_pcb, cloverpad-he.kicad_sch]
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2024-03-04 chore: remove chibi emotes from Cloverpad HE pcb
    they're unlikely to be recognisable at that size - only a few
    millimetres wide...
    [cloverpad-he.kicad_pcb]
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2024-03-10 feat(r2): initial attempt at shrinking case + pcb
    Case: 75x65mm, PCB: 60x50mm (57.5mm height including USB-C cutout)
    I'm able to get ~3mm wall thickness around the threaded inserts, which gives me a bit more confidence in the walls not cracking.
    [cloverpad-case.FCStd, cloverpad-he.kicad_pcb, cloverpad-he.kicad_sch]
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2024-06-09 chore: remove Cloverpad HE from rev. 1
    only ended up making the Cloverpad MX for this revision - will focus on it during rev. 2 anyway.
    [cloverpad-he.kicad_pcb, cloverpad-he.kicad_sch]
2024-06-09 feat: initial attempt at new case
    shrinking it is a bit difficult without knowing what's on the PCB - need to make sure I can route this...
    probably better to design the PCB first so I know what the minimum size is.
    [cloverpad-case.FCStd, minimal-pcb.kicad_pcb]
2024-06-09 feat: new schematic for rev. 2, with various fixes and component changes
    almost there - just need to figure out how to attach an EEPROM.
    [cloverpad-mx.kicad_pcb, cloverpad-mx.kicad_sch]
2024-06-09 feat: add external AT24C32 EEPROM
    for 3.3V, it seems that anything from 2k to 4.7k will work, but I've seen 10k working on Adafruit's EEPROM breakout. I've chosen 5.1k to minimise the BOM (the same ones used for USB).
    [cloverpad-mx.kicad_pcb, cloverpad-mx.kicad_sch]
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
